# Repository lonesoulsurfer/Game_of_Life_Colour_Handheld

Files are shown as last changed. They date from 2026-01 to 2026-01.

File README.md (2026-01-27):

	
UTUX1028

MCHT5886

Version 2 now includes the following tools:

	Sound: ON/OFF
	
	Volume: Low/Medium/High
	
	World: Toroid/Open
	
	Grid: ON/OFF
	
	Population: ON/OFF
	
	Trail Mode: ON/OFF

I have also included another alternative game called 'larger than life'.  This game uses larger neighbourhoods instead of just the immediate 8 neighbours.  You can check out the neighbour sizes by holding down button B!

Instructables - https://www.instructables.com/Conways-Game-of-Life-Handheld-COLOURED-Ve

Youtube - https://youtu.be/rWrENXPgask

Conway's Game of Life - Complete User Guide

Main Menu Navigation
    UP/DOWN: Navigate menu options
    
    B: Select menu item
    
    B: Go back to previous menu

Color Modes

	All game modes support color! Press UP + DOWN together to toggle.

Tools

Tools Menu Breakdown

	Sound: ON/OFF - Toggles all game sounds on or off

	Volume: Low/Medium/High

	World: Toroid/Open - Controls what happens at the edges of the game board
		
		Toroid = Wraparound edges (cells on the left edge are neighbors with cells on right edge, top wraps to bottom)
	
		Open = Hard edges (cells at the edge have fewer neighbors, no wraparound)
	
		Applies to ALL game modes (Conway's Life, Brian's Brain, Day & Night, Seeds, Cyclic CA)
	
		Default: Toroid (wraparound)

	Grid: ON/OFF - Shows/hides grid lines between cells
	
		Only visible when cell size is 3px or larger (not on Tiny 2px cells)
	
		Population: ON/OFF - Shows/hides the population counter overlay during gameplay

	Gen: Current generation number
	
		Pop: Current number of living cells

	Trail Mode: ON/OFF - Shows fading trails behind cells as they die
		
		In Mono mode = Gray fading trail (white → light gray → dark gray → black over 12 frames)
		
		In Color mode = Colored fading trail using age-based colors

During Gameplay

    UP: Increase speed (faster generations)
    
    DOWN: Decrease speed (slower generations)
    
    LEFT: Change cell size (Tiny → Small → Normal → Large)
    
    RIGHT: ReB/Regenerate current pattern
    
    UP + DOWN (together): Toggle COLOR/MONO mode
    
    B (short press): Return to menu
    
    B (2 second press): Show/hide game rules overlay

    RESET Button (hold 2 seconds): Enter bootloader mode for updates

Edit Mode (Custom games)

	D-Pad: Move cursor
	
	B (short press): Toggle cell on/off
	
	B (2 second press): Start game
	
	B: Return to menu

Main Menu Options
	PRESET - Classic Patterns
	
	Coe Ship - Spaceship that travels across the board
	
	Gosper Glider Gun - Continuously spawns gliders
	
	Diamond - 4-8-12 diamond pattern that evolves
	
	Pulsar - Achim's p144 oscillator (period-144 pattern)
	
	Glider - 56P6H1V0 spaceship pattern

RANDOM - Chaotic Evolution

	Unpredictable patterns emerge
	
	May stabilize into oscillators
	
	May die out completely
	
	Game shows statistics when it stabilizes or dies

SYMMETRIC -  Creates symmetric initial patterns with different sizes

	CUSTOM - Draw Your Own
	
	Step 1: Choose Cell Size
	
	Tiny (2px cells): 160x120 grid
	
	Small (3px cells): 106x80 grid
	
	Normal (4px cells): 80x60 grid
	
	Large (8px cells): 40x30 grid

Step 2: Edit Mode

	Red crosshair shows cursor position
	
	Cursor blinks at 4Hz for visibility
	
	White cells = alive, Black = dead
	
	Move with D-pad, toggle cells with B

Step 3: Run

	Hold B for 2 seconds to start
	
	While running, hold B for 800ms to return to edit mode
	
	Press B to return to menu

ALT GAMES - Alternative Cellular Automata

BRIAN'S BRAIN
	Small: Compact symmetric cluster
	
	Medium: Larger symmetric pattern (35% density)
	
	Large: Very large sparse pattern (18% density)
	
	Random: Scattered center-weighted distribution
	
	Custom: Draw your own pattern

DAY & NIGHT - Complementary rule B where birth/survival rules mirror each other.
	
	Very stable, creates intricate patterns
	
	Day/Night metaphor in color mode
	
	Often runs indefinitely

SEEDS - "Exploding" automaton where cells live for exactly 1 generation.
	
	Random: Auto-generated 4-way symmetric pattern
	
	Custom: Draw your own (choose cell size first)

CYCLIC CA - Multi-state cellular automaton where cells cycle through 6 states.

	VrtclSym: Vertical mirror symmetry
	
	4WayRot: 4-way rotational symmetry
	
	Random: Random pattern type and size

RULE EXPLORER - Create Custom Rules

	Choose from 9 famous rule variations:

	Conway (B3/S23) - Classic Game of Life

	HighLife (B36/S23) - Like Conway, with replicators

	Maze (B3/S12345) - Creates maze-like patterns

	Coral (B3/S45678) - Grows coral-like structures

	Seeds (B2/S) - Exploding patterns (same as Seeds mode)

	Replicator (B1357/S1357) - Self-replicating patterns

	2x2 (B36/S125) - Stable 2x2 blocks common

	NoDeath (B3/S012345678) - Cells never die once born

	Diamoeba (B35678/S5678) - Diamond-shaped amoebas

Custom Rules - Create your own rules:

	Navigation:
	
	UP/DOWN: Switch between Birth and Survival rows
	
	LEFT/RIGHT: Move cursor (0-8 neighbors)
	
	B (short): Toggle number on/off
	
	B (2 seconds): Start game with custom rules
	
	B: Back to preset menu

How It Works:

	Birth row: Select how many neighbors cause birth (0-8)
	
	Survival row: Select how many neighbors keep cell alive (0-8)
	
	Example: Conway's Life is B3 (birth on 3) / S23 (survive on 2 or 3)

Color Modes

	All game modes support color! Press UP + DOWN together to toggle.

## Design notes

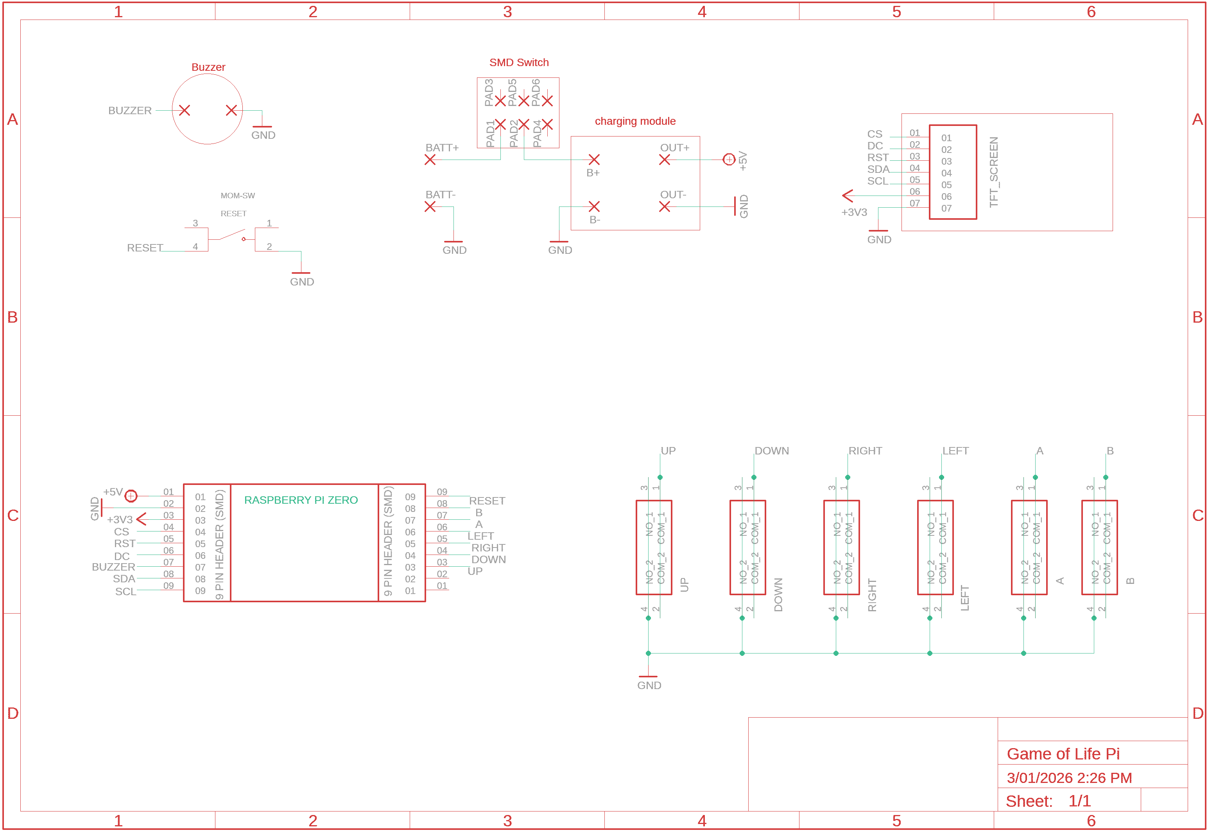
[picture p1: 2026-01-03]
Schematic.png

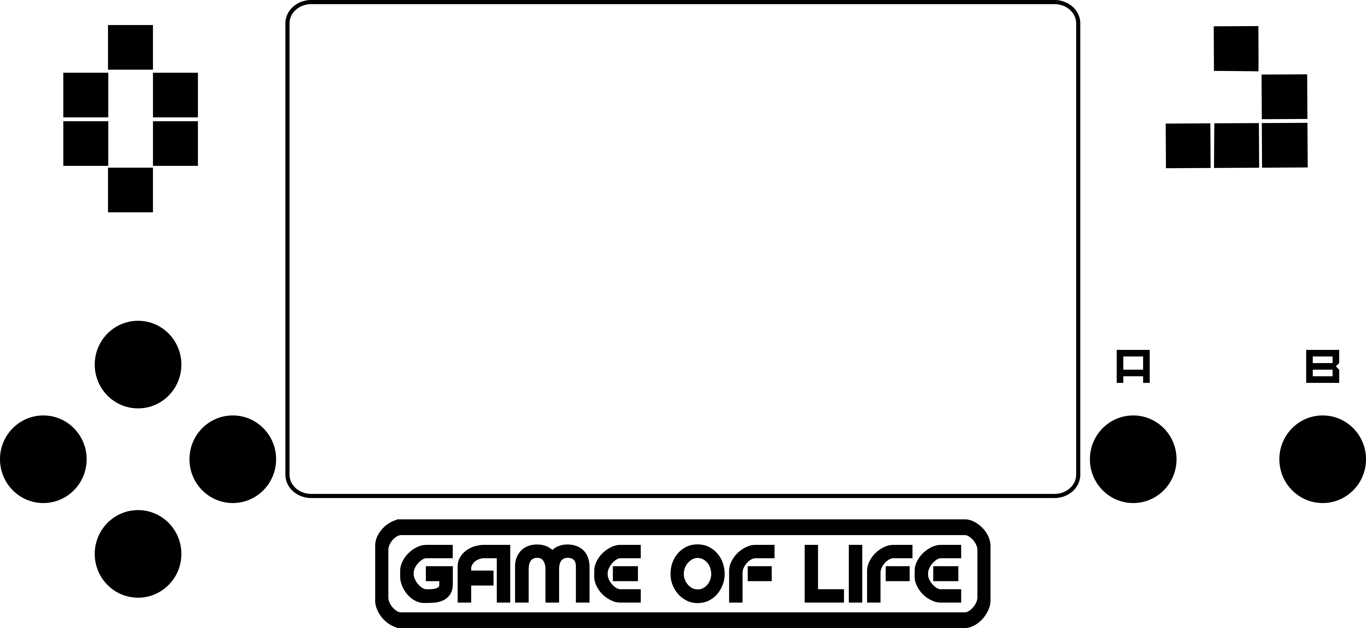
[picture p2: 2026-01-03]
Front Panel Design Files/Front Panel - Inkscape.png

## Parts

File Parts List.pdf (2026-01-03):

Part | Type | Part Number | Qty | Link | Image
Switches | Omron (11mm high) SMD Slide Switch (SMD) Tactile Tact Push Button -4 pin | MSK-22D27 | 6 1 1 | Link (https://www.aliexpress.com/item/1005007076344493.html) Link (https://www.aliexpress.com/w/wholesale-MSK%2525252d22D27-SMD-Sideslip.html?spm=a2g0o.detail.search.0) Link (https://www.aliexpress.com/item/1005006195658674.html?curPageLogUid=UlWXQG9WxOqp)

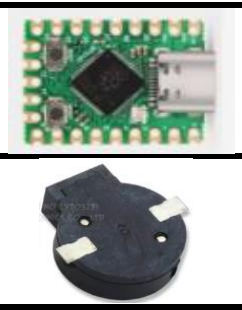
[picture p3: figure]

Raspberry Pi Pico Zero | | | 1 | Link (https://www.aliexpress.com/w/wholesale-Raspberry-PI-Pico-Mini-RP2040%2525252dZERO-Microcontroller.html)
Buzzer | Passive (9mm X 3.2mm) SMD | | 1 | Link (https://www.aliexpress.com/item/1005006870782289.html)

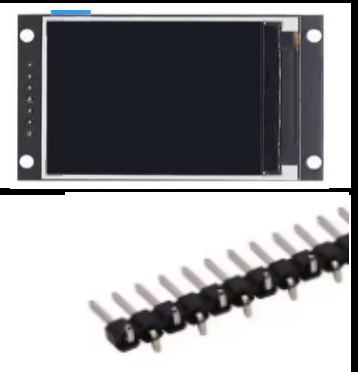
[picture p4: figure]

TFT Display | 2.0 inch OLED LCD Drive IC 240 x 320 | ST7789V | 1 | Link (https://www.aliexpress.com/w/wholesale-TFT-Display-2.0-inch-OLED-LCD-Drive-IC-ST7789V-240.html)
Header Pins | Male - SMT 2.54mm | | (2 X 9) | Link (https://www.aliexpress.com/item/1005008164411410.html)

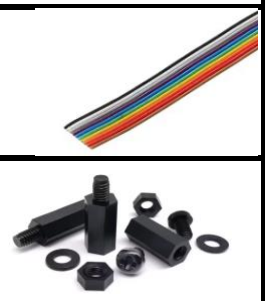
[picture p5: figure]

Ribbon Cable | Flat - 1.27mm | | 7P | Link (https://www.aliexpress.com/item/1005007868158870.html?curPageLogUid=TGqy8VLWcAFl)
Nylon Hex Spacers | M2 - assorted | | 1 | Link (https://www.aliexpress.com/item/1005007123661699.html)
Hex Socket Screw Kit | Ms - Assorted | DIN912 | 1 | Link (https://www.aliexpress.com/item/1005007273134914.html?curPageLogUid=XMboOUAJHQU8)
Battery | Lipo - (Mobile) | ab463446bu | 1 | Link (https://www.aliexpress.com/w/wholesale-ab463446bu.html?spm=a2g0o.detail.search.0)
Charging & Voltage Module | 3.7V To 9V 5V 2A DC-DC Step Up Boost Modul | | 1 | Link (https://www.aliexpress.com/item/1005005656423941.html?srcSns=sns_More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)

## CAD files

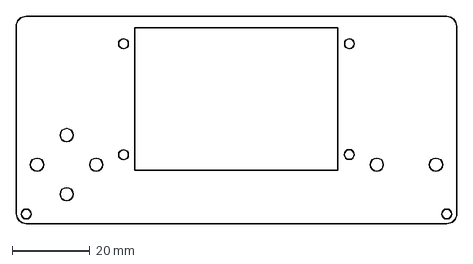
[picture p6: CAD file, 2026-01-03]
Front Panel Design Files/Game of Life - Fusion.dxf
113.3 x 53.3 mm

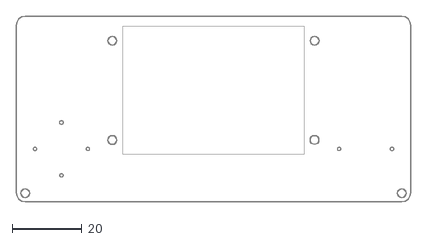
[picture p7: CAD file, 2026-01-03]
Front Panel Design Files/Game of Life PCB.dxf
113.3 x 53.3

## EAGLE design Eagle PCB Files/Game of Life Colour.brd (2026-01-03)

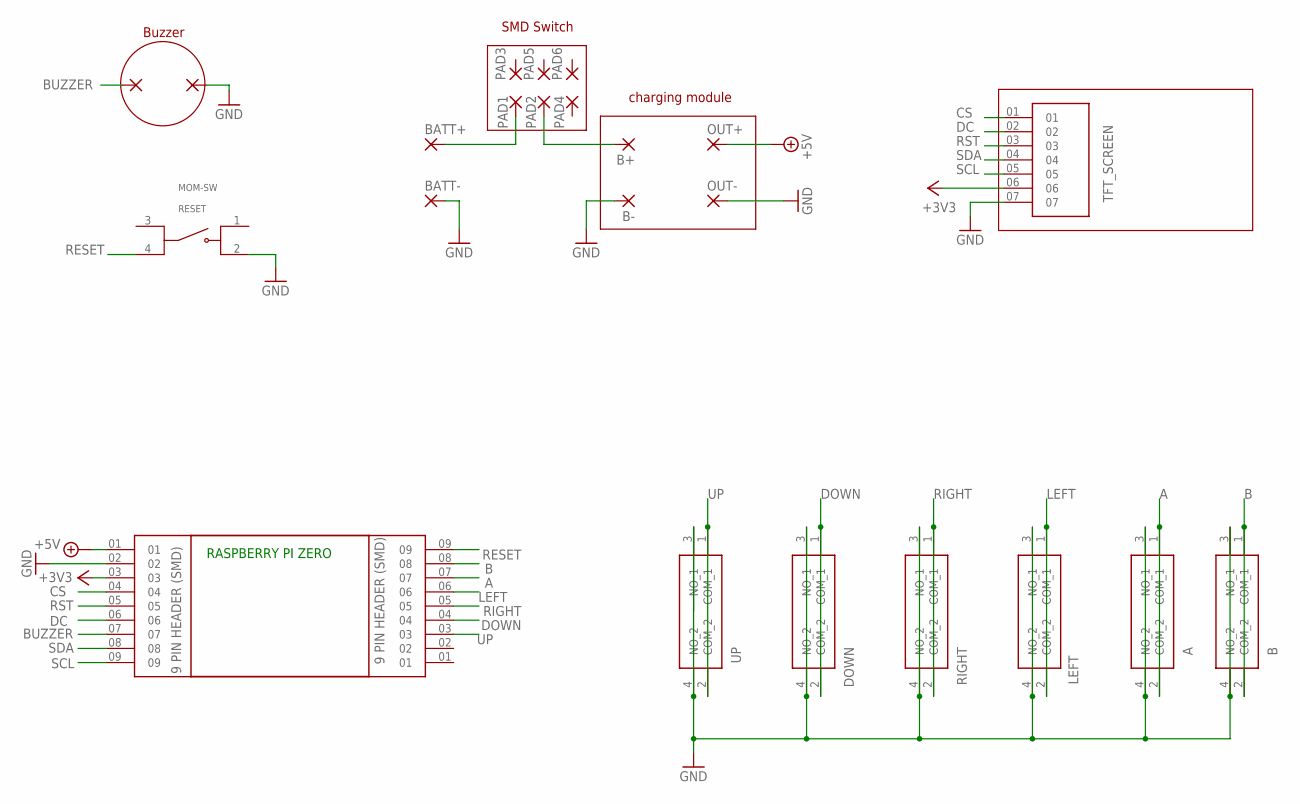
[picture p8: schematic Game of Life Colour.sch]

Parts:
A: 101-0364-EV; 1010364EV
B: 101-0364-EV; 1010364EV
B+: SMD5; SMD2,54-5,08
B-: SMD5; SMD2,54-5,08
BATT+: SMD5; SMD2,54-5,08
BATT-: SMD5; SMD2,54-5,08
DOWN: 101-0364-EV; 1010364EV
J2, J3: 9 PIN HEADER (SMD); SAMTEC_TMM-108-X-X-S-SM
LEFT: 101-0364-EV; 1010364EV
OUT+: SMD5; SMD2,54-5,08
OUT-: SMD5; SMD2,54-5,08
PAD1, PAD2, PAD3, PAD4, PAD5, PAD6, PAD7, PAD8: SMD2; SMD1,27-2,54
RESET: MOM-SW; SW_TS18-5-25-SL-260-SMT-TR
RIGHT: 101-0364-EV; 1010364EV
TFT_SCREEN: TMM-108-X-X-S-SM; SAMTEC_TMM-108-X-X-S-SM
UP: 101-0364-EV; 1010364EV

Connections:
+3V3: J3.03, TFT_SCREEN.06
+5V: J3.01, OUT+.1
A: A.1 (COM_1), A.2 (COM_2), J2.07
B: B.1 (COM_1), B.2 (COM_2), J2.08
BUZZER: J3.07, PAD7.1
CS: J3.04, TFT_SCREEN.01
DC: J3.06, TFT_SCREEN.02
DOWN: DOWN.1 (COM_1), DOWN.2 (COM_2), J2.04
GND: A.3 (NO_1), A.4 (NO_2), B.3 (NO_1), B.4 (NO_2), B-.1, BATT-.1, DOWN.3 (NO_1), DOWN.4 (NO_2), J3.02, LEFT.3 (NO_1), LEFT.4 (NO_2), OUT-.1, PAD8.1, RESET.2, RIGHT.3 (NO_1), RIGHT.4 (NO_2), TFT_SCREEN.07, UP.3 (NO_1), UP.4 (NO_2)
LEFT: J2.06, LEFT.1 (COM_1), LEFT.2 (COM_2)
unnamed: BATT+.1, PAD1.1
unnamed: B+.1, PAD2.1
RESET: J2.09, RESET.4
RIGHT: J2.05, RIGHT.1 (COM_1), RIGHT.2 (COM_2)
RST: J3.05, TFT_SCREEN.03
SCL: J3.09, TFT_SCREEN.05
SDA: J3.08, TFT_SCREEN.04
UP: J2.03, UP.1 (COM_1), UP.2 (COM_2)

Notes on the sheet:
charging module
SMD Switch
Buzzer
RASPBERRY PI ZERO

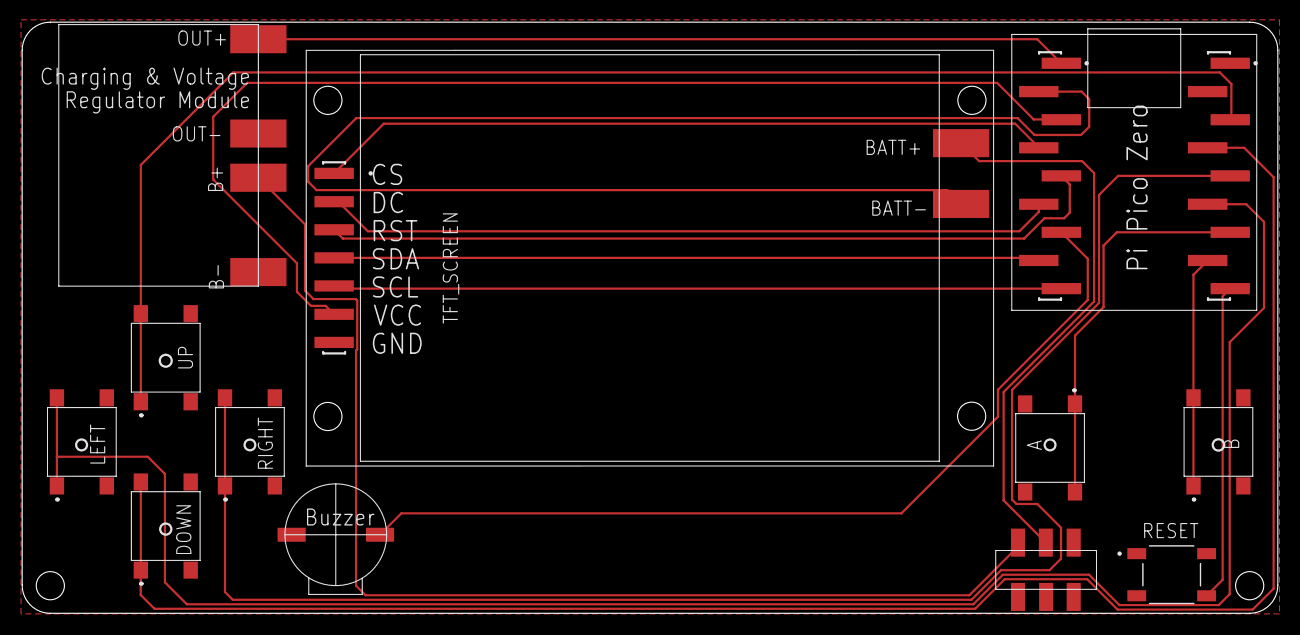
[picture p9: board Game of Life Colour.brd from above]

Board: 2 copper layers, 113.3 x 53.3 mm, 24 parts (0 on the bottom side), 18 nets.

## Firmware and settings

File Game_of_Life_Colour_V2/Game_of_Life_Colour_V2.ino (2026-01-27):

/*
 * =====================================================================
 *                    CONWAY'S GAME OF LIFE
 *                RP2040 + ST7789V TFT Implementation
 *                COMPLETE FULL SCREEN VERSION WITH VARIABLE CELL SIZE
 *                         NO FLASH UPDATE
 * =====================================================================
 * 
 * Complete rewrite using 2D boolean array for full screen coverage
 * Optimized to only update changed cells - eliminates screen flashing
 * Added variable cell size: Tiny (2px), Small (3px), Normal (4px)
 * 
 * HARDWARE REQUIREMENTS:
 * • Raspberry Pi Pico or RP2040-Zero
 * • ST7789V 2.0" TFT Display (240x320)
 * • 6 buttons on GPIO pins 2, 3, 4, 5, 6, 7
 * 
 * WIRING:
 * ST7789V TFT:
 *   VCC -> 3.3V, GND -> GND
 *   SCL -> GP18 (SPI0 SCK), SDA -> GP19 (SPI0 MOSI)
 *   RES/RST -> GP20, DC -> GP21, CS -> GP17
 * 
 * Buttons (connect between GPIO and GND):
 *   UP -> GP2, DOWN -> GP3, LEFT -> GP4
 *   RIGHT -> GP5, SET -> GP6, B -> GP7
 * 
 * NEW CONTROLS:
 *   During gameplay: LEFT = Change cell size, RIGHT = Reset
 * 
 * Libraries: Adafruit GFX, Adafruit ST7735 and ST7789
 * Board: Raspberry Pi Pico
 * =====================================================================
 */

#include <SPI.h>
#include <Adafruit_GFX.h>
#include <Adafruit_ST7789.h>
#include <EEPROM.h>

// EEPROM addresses for persistent settings
#define EEPROM_SOUND_ENABLED 0
#define EEPROM_SOUND_VOLUME 1

// TFT Display pins
#define TFT_CS        29
#define TFT_RST       28
#define TFT_DC        27

// SPI1 pins
#define TFT_MOSI      15  // SDA
#define TFT_SCK       14  // SCL

// Display dimensions
#define SCREEN_WIDTH 320
#define SCREEN_HEIGHT 240

// Maximum board dimensions (for Tiny cell size)
#define MAX_BOARD_WIDTH 160
#define MAX_BOARD_HEIGHT 120

// Button pins
#define BTN_UP_PIN    2
#define BTN_DOWN_PIN  3
#define BTN_LEFT_PIN  5 
#define BTN_RIGHT_PIN 4 
#define BTN_SET_PIN   6
#define BTN_B_PIN     7
#define BTN_RESET_PIN 8 
#define BUZZER_PIN    26

Adafruit_ST7789 display = Adafruit_ST7789(&SPI1, TFT_CS, TFT_DC, TFT_RST);

// Colors
#define COLOR_BLACK   0x0000
#define COLOR_WHITE   0xFFFF
#define COLOR_RED     0xF800
#define COLOR_GREEN   0x07E0
#define COLOR_BLUE    0x001F

// Cell size settings
int currentCellSize = 4;  // Default: Normal (4px)
int BOARD_WIDTH = 80;     // Will be recalculated based on cell size
int BOARD_HEIGHT = 60;    // Will be recalculated based on cell size

// Game boards - using maximum dimensions
bool board[MAX_BOARD_WIDTH][MAX_BOARD_HEIGHT];
bool newBoard[MAX_BOARD_WIDTH][MAX_BOARD_HEIGHT];

// Brian's Brain
bool briansBrain_dying[MAX_BOARD_WIDTH][MAX_BOARD_HEIGHT];
bool briansBrain_newDying[MAX_BOARD_WIDTH][MAX_BOARD_HEIGHT];

// Cyclic CA
uint8_t cyclicStates[MAX_BOARD_WIDTH][MAX_BOARD_HEIGHT];
uint8_t cyclicNewStates[MAX_BOARD_WIDTH][MAX_BOARD_HEIGHT];

int cyclicThreshold = 3;

// Game variables
uint32_t cellCount = 0;
uint32_t generation = 0;
uint32_t start_t = 0;
uint32_t frame_start_t = 0;
uint32_t max_cellCount = 0;
bool showingStats = false;
unsigned long statsStartTime = 0;
bool colorMode = false;
uint8_t cellAges[MAX_BOARD_WIDTH][MAX_BOARD_HEIGHT];  // Track how long cells have been alive
#define seedsAges cellAges  // Share arrays - never used simultaneously
unsigned long colorIndicatorTime = 0;
bool showingColorIndicator = false;
unsigned long cellSizeIndicatorTime = 0;
bool showingCellSizeIndicator = false;
bool showingRules = false;
unsigned long lastRuleToggle = 0;

// Rule Explorer variables
bool ruleExplorerMode = false;
uint8_t birthRule = 0b00001000;    // B3 (bit 3 set)
uint8_t survivalRule = 0b00001100; // S23 (bits 2,3 set)
bool inRuleExplorerMenu = false;
uint8_t ruleMenuSelection = 1;
bool inCustomRuleEdit = false;
uint8_t customEditRow = 0; // 0=birth, 1=survival
uint8_t customEditCursor = 3;
bool startedFromCustomRule = false; 

// Preset rules stored in PROGMEM to save RAM
struct Rule {
    const char* name;
    uint8_t birth;
    uint8_t survival;
};

// Store in program memory, not RAM
const Rule PRESET_RULES[] PROGMEM = {
    {"High Life", 0b01001000, 0b00001100},  // B36/S23 - Has replicator
    {"34 Life",   0b00011000, 0b00011000},  // B34/S34 - Crystalline
    {"Diamoeba",  0b11111000, 0b11111000},  // B35678/S5678 - Organic blobs
    {"Replicator",0b10101010, 0b10101010},  // B1357/S1357 - Self-copies
    {"Long Life", 0b00001000, 0b00100000},  // B3/S5 - Stable structures
    {"Maze",      0b00001000, 0b00111110},  // B3/S12345 - Maze patterns
    {"Coral",     0b00001000, 0b11111000},  // B3/S45678 - Coral growth
    {"2x2",       0b01001000, 0b00100010},  // B36/S125 - 2x2 blocks
    {"Dry Life",  0b10001000, 0b00001100},  // B37/S23 - Explodes slowly
    {"Amoeba",    0b10101000, 0b10101010},  // B357/S1357 - Chaotic blobs
    {"Coagulate", 0b10001000, 0b00001100},  // B37/S23 - Slow expand
    {"Gnarl",     0b00000010, 0b00000010},  // B1/S1 - Chaotic trails
};
const int NUM_PRESET_RULES = 12;

// Control variables
unsigned long last_button_check_time = 0;
uint8_t currentSpeedIndex = 0;
bool buttonProcessingInProgress = false;
uint8_t cursorX = 0;
uint8_t cursorY = 0;
bool editMode = true;
bool inMenuMode = true;
uint8_t menuSelection = 1;
uint8_t currentSymmetryType = 0;
uint8_t currentSymmetrySize = 0;
uint8_t dayNightDensitySelection = 1;

// Game modes
bool inPatternsSubMenu = false;
uint8_t patternSelection = 1;
uint8_t gameMode = 1;
const int frameDelays[] = {500, 400, 300, 250, 200, 150, 100, 75, 50, 40, 30, 25};
const int numSpeeds = sizeof(frameDelays) / sizeof(frameDelays[0]);
uint8_t currentBriansBrainSize = 1;

// Submenu variables
bool inSymmetricSubMenu = false;
uint8_t symmetricSizeSelection = 1;
bool inAltGamesSubMenu = false;
uint8_t altGameSelection = 1;
bool inSeedsSubMenu = false;
uint8_t seedsGameSelection = 1;
bool seedsWasCustom = false;
bool inDayNightSubMenu = false;
bool inCellSizeSubMenu = false;
uint8_t cellSizeSelection = 3;  // 1=Tiny, 2=Small, 3=Normal
uint8_t pendingGameMode = 0;     // Store which game mode triggered cell size menu
bool inToolsSubMenu = false;
uint8_t toolsSelection = 1;

// Tool settings
bool showGridLines = false;
bool showPopCounter = false;
bool trailMode = false;

// Game state
bool briansBrainMode = false;
bool inBriansBrainSubMenu = false;
uint8_t briansBrainSizeSelection = 1;
bool briansBrainWasCustom = false;
int briansBrain_lowCellCounter = 0;
bool briansBrainColorMode = false;

bool dayNightMode = false;
bool dayNightColorMode = false;
bool cyclicMode = false;
bool inCyclicSubMenu = false;
uint8_t cyclicSizeSelection = 1;
uint8_t currentCyclicSize = 1;
bool cyclicColorMode = false;
bool seedsMode = false;
bool seedsColorMode = false;

// Larger than Life
bool largerThanLifeMode = false;
bool inLargerThanLifeSubMenu = false;
uint8_t largerThanLifeSelection = 1;
uint8_t currentLargerThanLifeRule = 1;
bool largerThanLifeColorMode = false;
bool largerThanLifeSavedColorMode = false;

// LtL uses larger neighborhoods - we'll use 5x5 (range 2)
int ltl_range = 2;  // 2 = 5x5, 3 = 7x7, 4 = 9x9
int ltl_birthMin = 34;
int ltl_birthMax = 45;
int ltl_surviveMin = 34;
int ltl_surviveMax = 58;

// Sound settings
bool soundEnabled = true;
uint8_t soundVolume = 2;  // 0=Off, 1=Low, 2=Medium, 3=High

// World topology (applies to all games)
bool toroidalWorld = true;  // true = wraparound edges, false = open edges

// Function prototypes
void updateBoardDimensions();
void randomizeBoard();
void drawCell(int x, int y, uint16_t color);
void collectRandomness(int ms);
void handleDirectionalButtons();
void handleSetButton();
void handleButtonB();
void handleRuleExplorerButtons();
void playMenuBeep();
bool isBtnReset();
void drawCursor();
void clearBoard();
void showMenu();
void showGameStatistics();
void startShowingStats();
void loadPresetPattern(int patternId);
void generateSymmetricPattern(int symmetryType);
void generateVerticalSymmetric();
void generateHorizontalSymmetric();
void generateRotationalSymmetric();
void generateSmallSymmetricPattern(int symmetryType);
void generateMediumSymmetricPattern(int symmetryType);
void updateDayNight();
void drawDayNight();
void initializeDayNight();
void updateCyclic();
void drawCyclic();
void initializeCyclic();
void updateSeeds();
void drawSeeds();
void initializeSeeds();
void updateBriansBrain();
void drawBriansBrain();
void toggleCellAtCursor();
void showGameRules();
void generateBriansBrainSmall();
void generateBriansBrainMedium();
void generateBriansBrainLarge();
void generateBriansBrainRandom();
void updateGame();
void drawBoard();
void changeCellSize();
void showCellSizeIndicator();
uint16_t getColorByAge(uint8_t age);
void drawRuleIndicator();
void showRuleExplorerMenu();
void initializeLargerThanLife();
void updateLargerThanLife();
void drawLargerThanLife();
void setLargerThanLifeRule(int ruleNum);

// Button functions
bool isBtnUp() { return digitalRead(BTN_UP_PIN) == LOW; }
bool isBtnDown() { return digitalRead(BTN_DOWN_PIN) == LOW; }
bool isBtnLeft() { return digitalRead(BTN_LEFT_PIN) == LOW; }
bool isBtnRight() { return digitalRead(BTN_RIGHT_PIN) == LOW; }
bool isBtnSet() { return digitalRead(BTN_SET_PIN) == LOW; }
bool isBtnB() { return digitalRead(BTN_B_PIN) == LOW; }
bool isBtnReset() { return digitalRead(BTN_RESET_PIN) == LOW; }

void resetDrawFlags() {
    // Forces all draw functions to redraw from scratch
    // This is a workaround - the actual fix is in each draw function
}

void updateBoardDimensions() {
    BOARD_WIDTH = SCREEN_WIDTH / currentCellSize;
    BOARD_HEIGHT = SCREEN_HEIGHT / currentCellSize;
    cursorX = BOARD_WIDTH / 2;
    cursorY = BOARD_HEIGHT / 2;
}

void showCellSizeIndicator() {
    // Show a brief indicator of the new cell size
    display.fillRect(SCREEN_WIDTH - 60, 5, 55, 20, COLOR_BLACK);
    display.setTextSize(1);
    display.setTextColor(COLOR_WHITE);
    display.setCursor(SCREEN_WIDTH - 58, 10);
    
    switch(currentCellSize) {
        case 2: display.print("Tiny"); break;
        case 3: display.print("Small"); break;
        case 4: display.print("Normal"); break;
        case 8: display.print("Large"); break;
    }
    
    // Set timer for indicator
    cellSizeIndicatorTime = millis();
    showingCellSizeIndicator = true;
}
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
void loop() {
    // Check for bootloader button press on GP1
    static unsigned long bootloaderButtonPressStart = 0;
    static bool bootloaderButtonPressed = false;
    
    if (isBtnReset() && !bootloaderButtonPressed) {
        bootloaderButtonPressed = true;
        bootloaderButtonPressStart = millis();
    }
    
    if (isBtnReset() && bootloaderButtonPressed && (millis() - bootloaderButtonPressStart >= 2000)) {
        // Long press (2 seconds) = enter bootloader mode
        display.fillScreen(COLOR_BLACK);
        display.setTextSize(2);
        display.setTextColor(COLOR_WHITE);
        display.setCursor(20, 100);
        display.println("BOOTLOADER MODE");
        display.setCursor(20, 130);
        display.println("Ready for upload");
        delay(500);
        rp2040.rebootToBootloader();  // Enter USB bootloader mode
    }
    
    if (!isBtnReset() && bootloaderButtonPressed) {
        bootloaderButtonPressed = false;
    }
    
    if (briansBrainMode && editMode && !briansBrainWasCustom) {
        editMode = false;
    }
    
    if (inRuleExplorerMenu) {
        handleRuleExplorerButtons();
        return;
    }
    
    handleDirectionalButtons();
    handleSetButton();
    handleButtonB();
    
    if (inMenuMode) {
        return;
    }
    
    if (!editMode) {
        unsigned long current_time = millis();
        
        // Don't update game if showing rules
        if (showingRules) {
            return;
        }
        
        // Clear color mode indicator after 2 seconds
        if (showingColorIndicator && (current_time - colorIndicatorTime >= 2000)) {
            showingColorIndicator = false;
            // Clear the indicator area by redrawing affected cells
            for (int x = (SCREEN_WIDTH - 60) / currentCellSize; x < SCREEN_WIDTH / currentCellSize; x++) {
                for (int y = 5 / currentCellSize; y < 25 / currentCellSize; y++) {
                    if (x >= 0 && x < BOARD_WIDTH && y >= 0 && y < BOARD_HEIGHT) {
                        if (board[x][y]) {
                            if (colorMode && gameMode >= 1 && gameMode <= 4) {
                                drawCell(x, y, getColorByAge(cellAges[x][y]));
                            } else {
                                drawCell(x, y, COLOR_WHITE);
                            }
                        } else {
                            drawCell(x, y, COLOR_BLACK);
                        }
                    }
                }
            }
        }
        
        // Clear cell size indicator after 2 seconds
        if (showingCellSizeIndicator && (current_time - cellSizeIndicatorTime >= 2000)) {
            showingCellSizeIndicator = false;
            
            // Clear the indicator area (black rectangle + text area)
            display.fillRect(SCREEN_WIDTH - 60, 5, 55, 20, COLOR_BLACK);
            
            // Redraw affected cells in that area
            int startX = (SCREEN_WIDTH - 60) / currentCellSize;
            int endX = SCREEN_WIDTH / currentCellSize;
            int startY = 5 / currentCellSize;
            int endY = 25 / currentCellSize;
            
            for (int x = startX; x <= endX && x < BOARD_WIDTH; x++) {
                for (int y = startY; y <= endY && y < BOARD_HEIGHT; y++) {
                    if (x >= 0 && x < BOARD_WIDTH && y >= 0 && y < BOARD_HEIGHT) {
                        // Determine which game mode and color mode
                        if (briansBrainMode) {
                            // Redraw Brian's Brain cells
                            bool isAlive = board[x][y];
                            bool isDying = briansBrain_dying[x][y];
                            
                            if (briansBrainColorMode) {
                                if (isAlive && !isDying) {
                                    drawCell(x, y, 0x07FF); // Cyan
                                } else if (isDying) {
                                    uint8_t age = cellAges[x][y]; // Using cellAges for trail
                                    if (age <= 3) drawCell(x, y, 0xFFFF);
                                    else if (age <= 6) drawCell(x, y, 0xFFE0);
                                    else if (age <= 9) drawCell(x, y, 0xFD20);
                                    else if (age <= 12) drawCell(x, y, 0xF800);
                                    else if (age <= 15) drawCell(x, y, 0x780F);
                                    else if (age <= 18) drawCell(x, y, 0x4008);
                                    else drawCell(x, y, COLOR_BLACK);
                                } else {
                                    drawCell(x, y, COLOR_BLACK);
                                }
                            } else {
                                // Mono mode - don't redraw (blinking handled elsewhere)
                                if (isAlive && !isDying) {
                                    drawCell(x, y, COLOR_WHITE);
                                } else {
                                    drawCell(x, y, COLOR_BLACK);
                                }
                            }
                        } else if (dayNightMode) {
                            if (dayNightColorMode) {
                                if (board[x][y]) {
                                    drawCell(x, y, getDayNightColorByAge(cellAges[x][y], true));
                                } else if (cellAges[x][y] > 0) {
                                    drawCell(x, y, getDayNightColorByAge(cellAges[x][y], false));
                                } else {
                                    drawCell(x, y, COLOR_BLACK);
                                }
                            } else {
                                drawCell(x, y, board[x][y] ? COLOR_WHITE : COLOR_BLACK);
                            }
                        } else if (seedsMode) {
                            if (seedsColorMode) {
                                uint8_t age = seedsAges[x][y];
                                if (age == 0 && board[x][y]) drawCell(x, y, 0xFFFF);
                                else if (age == 1) drawCell(x, y, COLOR_BLACK);
                                else if (age == 2) drawCell(x, y, 0x07FF);
                                else if (age == 3) drawCell(x, y, COLOR_BLACK);
                                else if (age == 4) drawCell(x, y, 0x001F);
                                else if (age == 5) drawCell(x, y, 0x780F);
                                else if (age == 6) drawCell(x, y, 0xF81F);
                                else if (age == 7) drawCell(x, y, 0xF800);
                                else if (age == 8) drawCell(x, y, 0xFD20);
                                else if (age == 9) drawCell(x, y, 0xFFE0);
                                else if (age == 10) drawCell(x, y, 0x8410);
                                else if (age == 11) drawCell(x, y, 0x2104);
                                else drawCell(x, y, COLOR_BLACK);
                            } else {
                                drawCell(x, y, board[x][y] ? COLOR_WHITE : COLOR_BLACK);
                            }
                        } else if (cyclicMode) {
                            if (cyclicColorMode) {
                                uint8_t state = cyclicStates[x][y];
                                uint16_t color;
                                switch(state) {
                                    case 0: color = COLOR_BLACK; break;
                                    case 1: color = 0xF800; break;
                                    case 2: color = 0xFD20; break;
                                    case 3: color = 0x07E0; break;
                                    case 4: color = 0x07FF; break;
                                    case 5: color = 0xF81F; break;
                                }
                                drawCell(x, y, color);
                            } else {
                                // Mono mode - just clear to black
                                drawCell(x, y, COLOR_BLACK);
                            }
                        } else if (largerThanLifeMode) {
                            if (largerThanLifeColorMode) {
                                if (board[x][y]) {
                                    drawCell(x, y, getColorByAge(cellAges[x][y]));
                                } else {
                                    drawCell(x, y, COLOR_BLACK);
                                }
                            } else {
                                drawCell(x, y, board[x][y] ? COLOR_WHITE : COLOR_BLACK);
                            }
                        } else if (ruleExplorerMode || (gameMode >= 1 && gameMode <= 4)) {
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
